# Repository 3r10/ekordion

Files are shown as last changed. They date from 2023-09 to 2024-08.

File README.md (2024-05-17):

# EKordion

## Introduction

Creation of a digital button accordion. *EK* could mean :

- The author's initials.
- *Electronic Keyboard*.

## Hardware

### PCBs *(designed with Kicad)*

+ Right hand PCB
  - 35 Cherry MX switches
  - 5 shift registers (74hc165)
  - Daisy-chain : *not implemented*
  - 6 pin connector to be connected to a micro-controller *(Arduino, ESP32, ...)*
  - Pull-down resistors : pushing buttons means high level
+ Left hand PCB :
  - 24 Cherry MX switches
  - 3 shift registers (74hc165)
  - Daisy-chain : *available*
  - 7 pin output connector to be connected to a micro-controller *(Arduino, ESP32, ...)*
  or another PCB
  - Jumper for CLK INH pull-down
  - 6 pin input connector to be connected to another PCB
  - Jumper for serial input pull-up
  - Pull-up resistors : pushing buttons means low level.

### 3D prints and laser cut *(designed with OpenSCAD)*

+ Right hand
  - 35 button caps to fit the Cherry MX switches
+ Left hand 
  - 24 button caps to fit the CHerry MX switches with offset to allow 
  the required layout.
  - laser cutted grid

## Software

### ESP32 *(IDF environment)*

Polyphonic sound synthesizer.

+ Keyboard inputs via GPIOs
+ Sound output via I2S protocol and external DAC.
+ Control of synthesis parameters via classic bluetooth
+ Synthesis engine :
  - Three instruments : bass, chords, lead
  - Wavetable synthesis
  - 10 polyphonic sounds *(may be more)*
  - Vibrato
  - Small reverberation

### Android app *(Android Studio)*

+ Control of synthesis parameters via classic bluetooth

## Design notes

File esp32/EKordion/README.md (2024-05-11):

```sh
. $HOME/esp/esp-idf/export.sh
sudo chmod a+rw /dev/ttyUSB0
```

### Configure the Project

```sh
idf.py menuconfig
```

### Build and Flash

Build the project and flash it to the board, then run monitor tool to view serial output:

```sh
idf.py -p /dev/ttyUSB0 flash monitor
```

(To exit the serial monitor, type ``Ctrl-]``.)

See the Getting Started Guide for full steps to configure and use ESP-IDF to build projects.

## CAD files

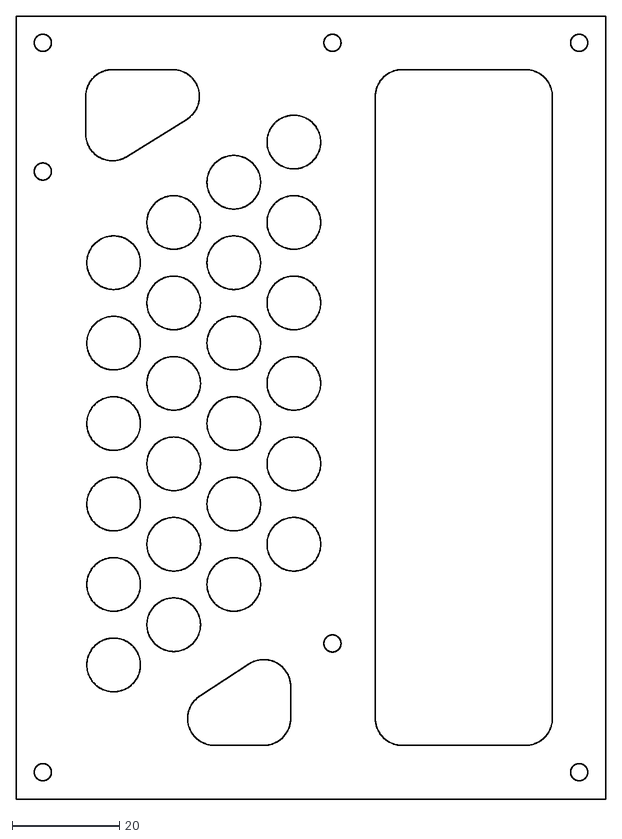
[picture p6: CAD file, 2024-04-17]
openscad/left_hand_buttons/left_hand_buttons_laser_cut.dxf
110.0 x 146.0

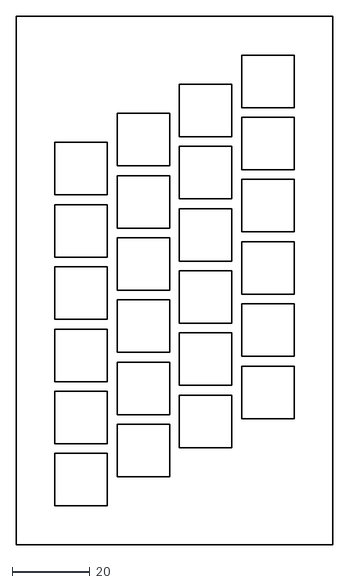
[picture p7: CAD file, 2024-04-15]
openscad/left_hand_soldering_jig/left_hand_soldering_jig.dxf
81.5 x 136.0

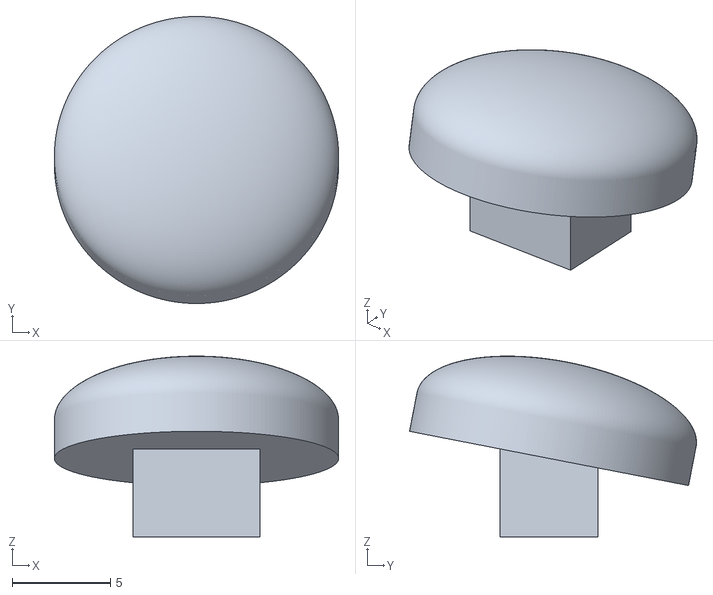
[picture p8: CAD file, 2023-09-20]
openscad/right_hand_button/right_hand_button.stl
14.5 x 14.6 x 9.22

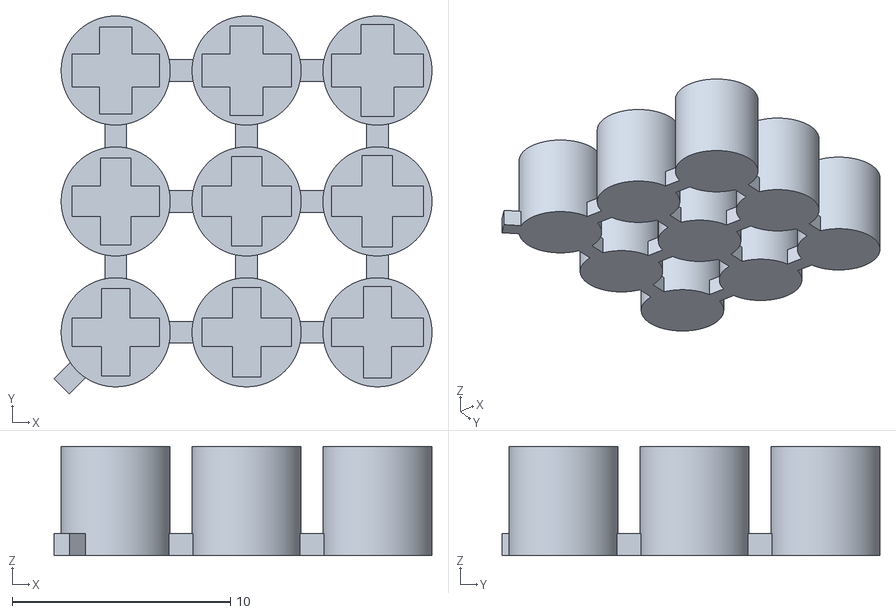
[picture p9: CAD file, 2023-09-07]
openscad/right_hand_button_test.stl
17.3 x 17.3 x 5.00

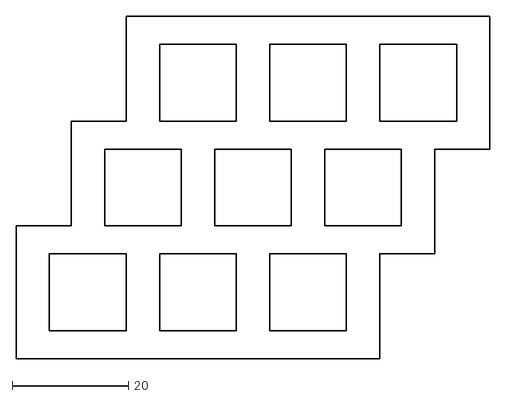
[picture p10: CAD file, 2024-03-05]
openscad/right_hand_soldering_jig/right_hand_soldering_jig.dxf
81.3 x 58.8

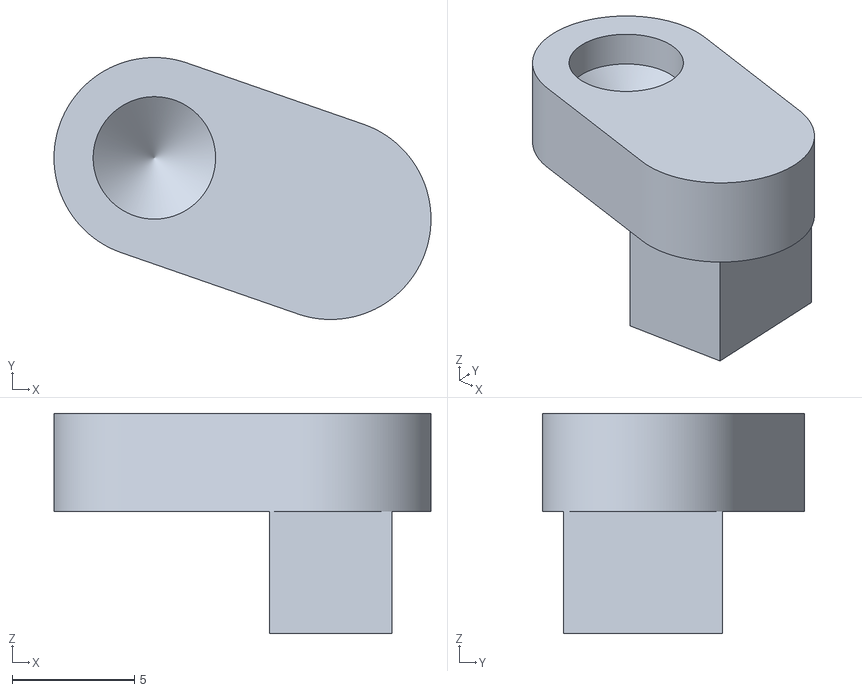
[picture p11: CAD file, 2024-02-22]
openscad/left_hand_buttons/left_hand_buttons_base.stl
15.4 x 10.7 x 9.00

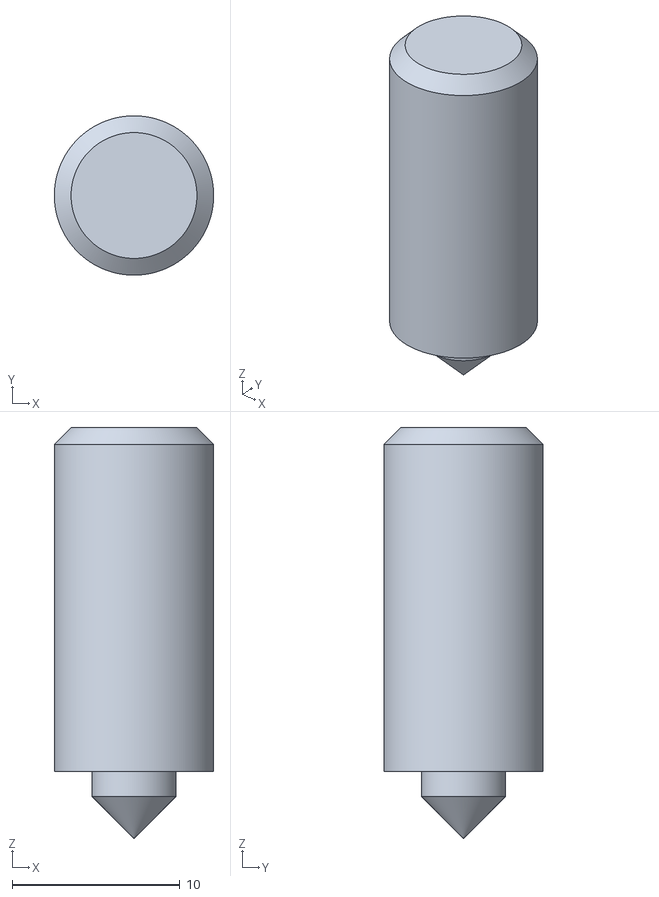
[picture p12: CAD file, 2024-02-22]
openscad/left_hand_buttons/left_hand_buttons_button.stl
9.50 x 9.50 x 24.5

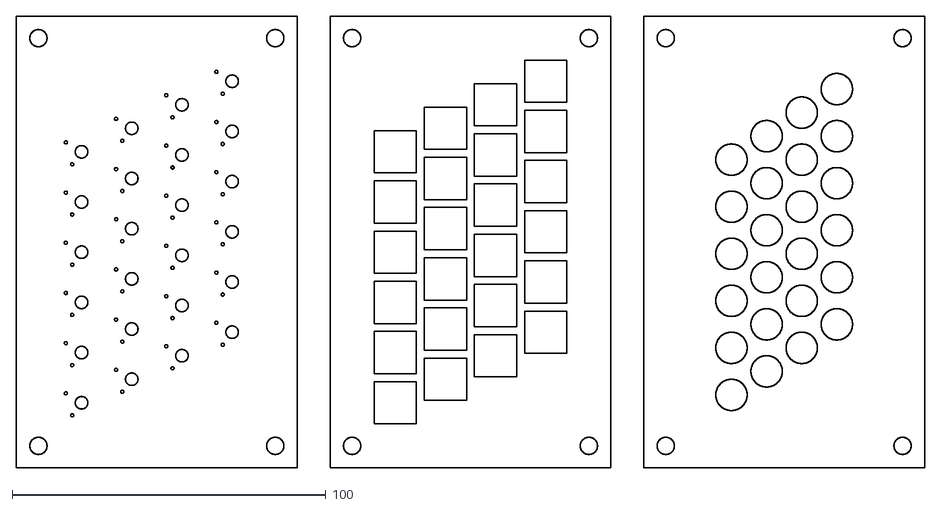
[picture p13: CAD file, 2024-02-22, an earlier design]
openscad/old_designs/left_hand_buttons_laser_cut.dxf
289.5 x 144.0

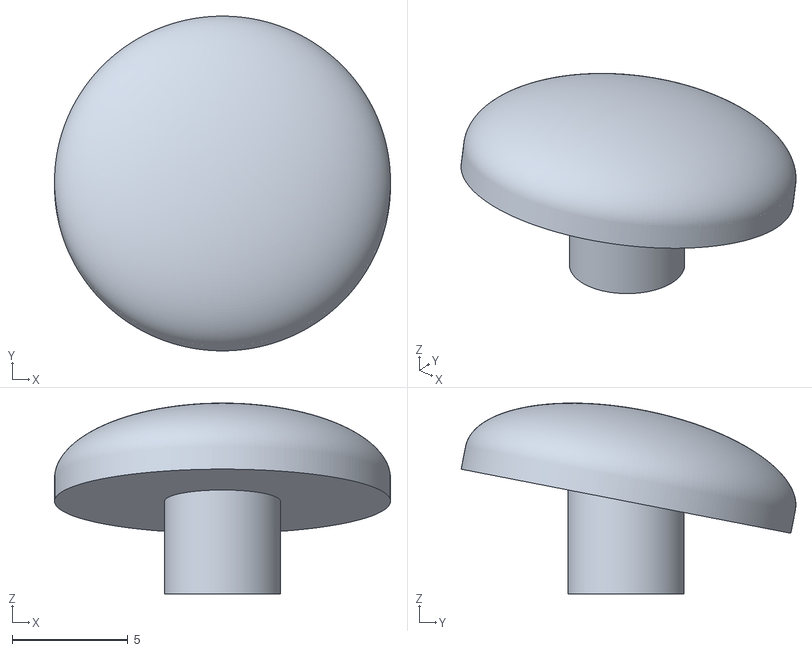
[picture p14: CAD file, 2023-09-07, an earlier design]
openscad/old_designs/right_hand_button.stl
14.5 x 14.4 x 8.23

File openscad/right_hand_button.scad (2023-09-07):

$fn=200;
angle = 11; // 11
buttonDiameter = 14.5;
buttonHeight1 = 3;
buttonHeight2 = 1;
pinDiameter = 5;
pinHeight = 4;
crossLength = 4;
crossWidth = 1.3;
crossDepth = 3.6;

buttonRadius = buttonDiameter/2;
pinRadius = pinDiameter/2;

union() {
	rotate(angle,[-1,0,0])
	translate ([0,0,buttonHeight2])
	union() {
		// top part (tilted)
		scale([1,1,buttonHeight1/buttonRadius])
		difference() {
			sphere(buttonRadius);
			translate([0,0,-buttonRadius]) cube([buttonDiameter,buttonDiameter,buttonDiameter],center=true);
		}
		translate([0,0,-buttonHeight2])
		cylinder(buttonHeight2,buttonRadius,buttonRadius);
	}
	translate([0,0,-pinHeight])
	// interface with CHerry MX switch
	difference() {
		cylinder(pinHeight+pinRadius*tan(angle),pinRadius,pinRadius);
		union() {
			translate([-crossLength/2,-crossWidth/2,-crossDepth]) 
			cube([crossLength,crossWidth,crossDepth*2]);
			translate([-crossWidth/2,-crossLength/2,-crossDepth]) 
			cube([crossWidth,crossLength,crossDepth*2]);
		}
	}
}

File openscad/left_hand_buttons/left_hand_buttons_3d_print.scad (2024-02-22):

$fn=200;

buttonPinDiameter = 9.5;

buttonsNumberX = 4;
buttonsNumberY = 6;
buttonsSpacingX = 11.2;
buttonsSpacingY = 15;
buttonsRankShiftY = 7.5;
buttonsRankShiftZ = 2.5;

buttonsBaseHeight = 13; // 10mm + box width

linkHeight = 4;
plugRadius = 2.5;

switchSpacingX = 16;
switchSpacingY = 16;
switchLengthX = 5;
switchLengthY = 6.5;
switchCrossLength = 4;
switchCrossWidth = 1.3;
switchCrossDepth = 3.6;
switchHeight = 5;





globalDeltaX = (switchSpacingX-buttonsSpacingX)*1.5;
globalDeltaY = (switchSpacingY-buttonsSpacingY)*2.5;

// Deduced from other dimensions
buttonPinRadius = buttonPinDiameter/2;
linkWidth = sqrt(switchLengthX^2+switchLengthY^2);
linkRadius = linkWidth/2;

for (i = [0:buttonsNumberX-1],j = [0:buttonsNumberY-1]) {
// for (i = [buttonsNumberX-1],j = [0]) {
    // Buttons
    buttonX = i*buttonsSpacingX+globalDeltaX;
    buttonY = j*buttonsSpacingY+i*buttonsRankShiftY+globalDeltaY;
    buttonZ = switchHeight;
    translate([buttonX,buttonY,buttonZ])
    union() {
        cylinder(plugRadius,0,plugRadius);
        translate([0,0,plugRadius])
        cylinder(linkHeight-plugRadius,plugRadius,plugRadius);
        h = buttonsBaseHeight+i*buttonsRankShiftZ;
        translate([0,0,linkHeight])
        cylinder(h-1,buttonPinRadius,buttonPinRadius);
        translate([0,0,linkHeight+h-1])
        cylinder(1,buttonPinRadius,buttonPinRadius-1);

    }
    // Switches
    switchX = i*switchSpacingX;
    switchY = j*switchSpacingY+i*buttonsRankShiftY;
    deltaX = switchX-buttonX;
    deltaY = switchY-buttonY;
    angle = atan2(deltaX,deltaY)+90;
    distance = sqrt(deltaX^2+deltaY^2);
    translate([switchX,switchY,0])
    difference() {
	    union() {
            translate([-switchLengthX/2,-switchLengthY/2,0])
        	cube([switchLengthX,switchLengthY,switchHeight]);
            rotate(-angle,[0,0,1])
            translate([0,0,switchHeight])
            difference() {
                union() {
                    translate([0,-linkWidth/2,0])
                    cube([distance,linkWidth,linkHeight]);
                    cylinder(linkHeight,linkRadius,linkRadius);
                    translate([distance,0,0])
                    cylinder(linkHeight,linkRadius,linkRadius);

                }
                union() {
                    translate([distance,0,0])
                    cylinder(plugRadius,0,plugRadius);
                    translate([distance,0,plugRadius])
                    cylinder(linkHeight-plugRadius+1,plugRadius,plugRadius);
                }
            }
        }
		union() {
			cube([switchCrossLength,switchCrossWidth,switchCrossDepth*2],true);
			cube([switchCrossWidth,switchCrossLength,switchCrossDepth*2],true);
		}
	}          
}

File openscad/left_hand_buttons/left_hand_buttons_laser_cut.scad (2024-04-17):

$fn=200;

globalLengthX = 110;
globalLengthY = 146;

centerDeltaX = 35;
centerDeltaY = 73.75;

buttonPinDiameter = 10;

buttonsNumberX = 4;
buttonsNumberY = 6;
buttonsSpacingX = 11.2;
buttonsSpacingY = 15;
buttonsRankShiftY = 7.5;

mountingHolesRadius = 1.6;

buttonPinRadius = buttonPinDiameter/2;

difference() {
    square([globalLengthX,globalLengthY]);
    union() {
        translate([67+buttonPinRadius,10+buttonPinRadius])
        minkowski() {
            square([33-2*buttonPinRadius,126-2*buttonPinRadius]);
            circle(buttonPinRadius);
        }
        minkowski() {
            polygon([
                [29.2,136-buttonPinRadius],
                [18,124],
                [18,136-buttonPinRadius],
            ]);
            circle(buttonPinRadius);
        }
        minkowski() {
            polygon([
                [35+2,10+buttonPinRadius],
                [35+11.2,10+buttonPinRadius],
                [35+11.2,21]
            ]);
            circle(buttonPinRadius);
        }
        translate([5,5])
        circle(mountingHolesRadius);
        translate([5,141])
        circle(mountingHolesRadius);
        translate([5,117])
        circle(mountingHolesRadius);
        translate([59,29])
        circle(mountingHolesRadius);
        translate([59,141])
        circle(mountingHolesRadius);
        translate([105,5])
        circle(mountingHolesRadius);
        translate([105,141])
        circle(mountingHolesRadius);
        translate([centerDeltaX,centerDeltaY])
        union() {
            // circle(1);
            for (i = [0:buttonsNumberX-1],j = [0:buttonsNumberY-1]) {
                buttonX = (1.5-i)*buttonsSpacingX;
                buttonY = (2.5-j)*buttonsSpacingY+(1.5-i)*buttonsRankShiftY;
                translate([buttonX,buttonY])
                circle(buttonPinRadius);
            }
        }
    }
}

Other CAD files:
openscad/left_hand_soldering_jig/left_hand_soldering_jig.scad
openscad/old_designs/left_hand_buttons_laser_cut.scad
openscad/old_designs/right_hand_button_test.scad
openscad/right_hand_button/right_hand_button.scad
openscad/right_hand_button_test.scad
openscad/right_hand_soldering_jig/right_hand_soldering_jig.scad

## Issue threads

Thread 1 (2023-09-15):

tu devrais choisir une license et creer le fichier LICENCE associe a ton projet.

goblinrieur, 2023-09-15:
salut

tu devrais choisir un e license et creer le fichier LICENCE associe a ton projet
Mettre un lien vers ta video et des photos/screenshots dans ton readme egallement ;)

pour les licences y a le choix
-MIT
-nolicence
-gpl*
-etc...

a toi de choisir ;)

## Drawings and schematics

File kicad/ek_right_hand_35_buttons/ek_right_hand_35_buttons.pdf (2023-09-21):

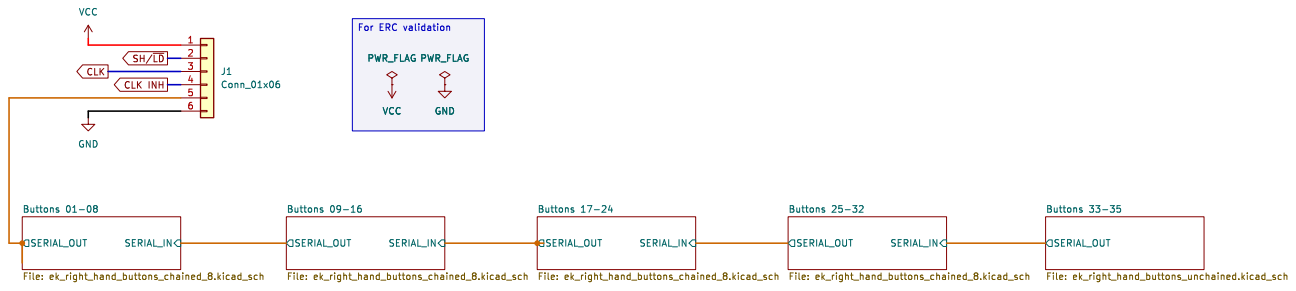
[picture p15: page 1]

SH/~{LD} CLK INH

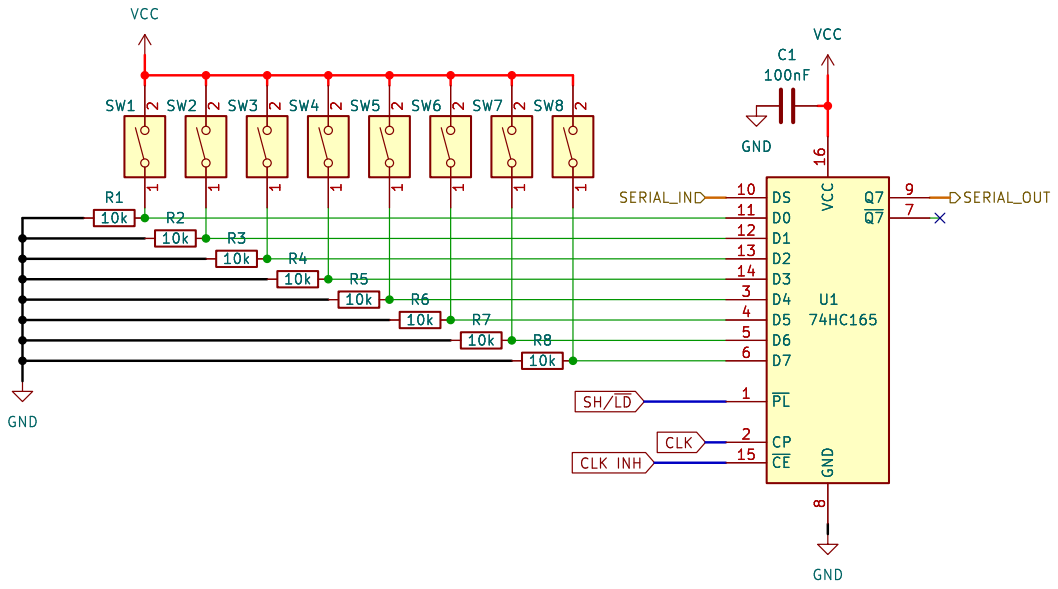
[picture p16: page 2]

1 SW4 2 ~{PL} 1 DS 10 D0 11 D1 12 D2 13 D3 14 ~{CE} 15 VCC 16 CP 2 D4 3 D5 4 D6 5 D7 6 ~{Q7} 7 GND

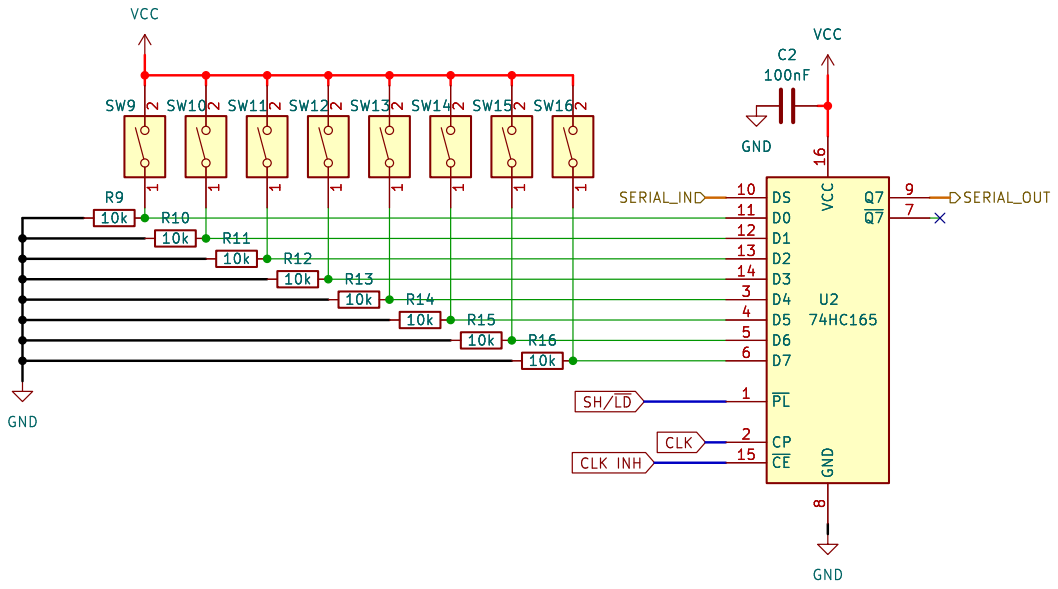
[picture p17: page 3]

1 SW12 2 ~{PL} 1 DS 10 D0 11 D1 12 D2 13 D3 14 ~{CE} 15 VCC 16 CP 2 D4 3 D5 4 D6 5 D7 6 ~{Q7} 7 GND

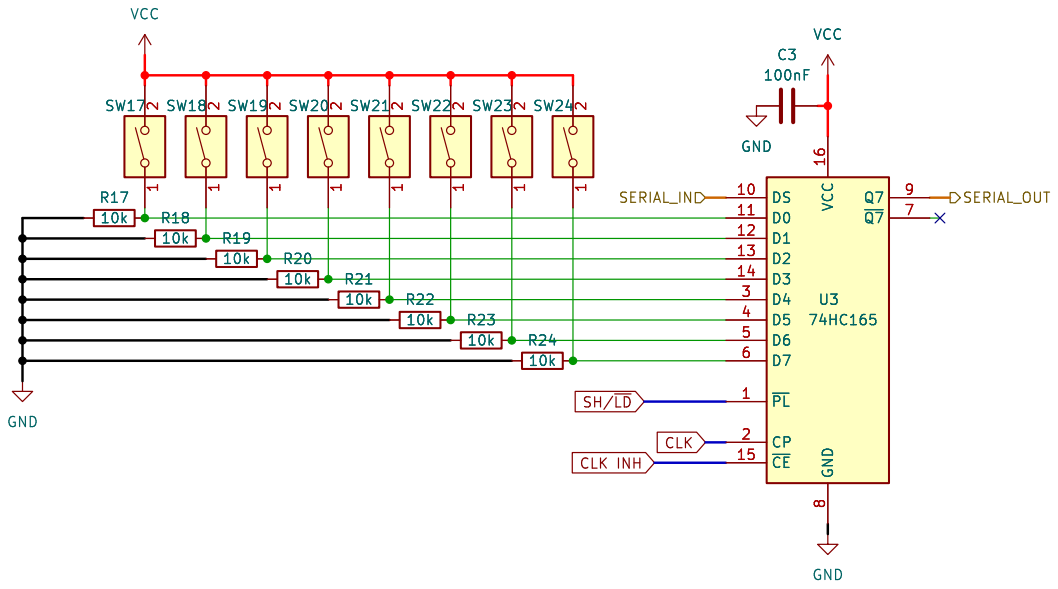
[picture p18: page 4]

1 SW20 2 ~{PL} 1 DS 10 D0 11 D1 12 D2 13 D3 14 ~{CE} 15 VCC 16 CP 2 D4 3 D5 4 D6 5 D7 6 ~{Q7} 7 GND

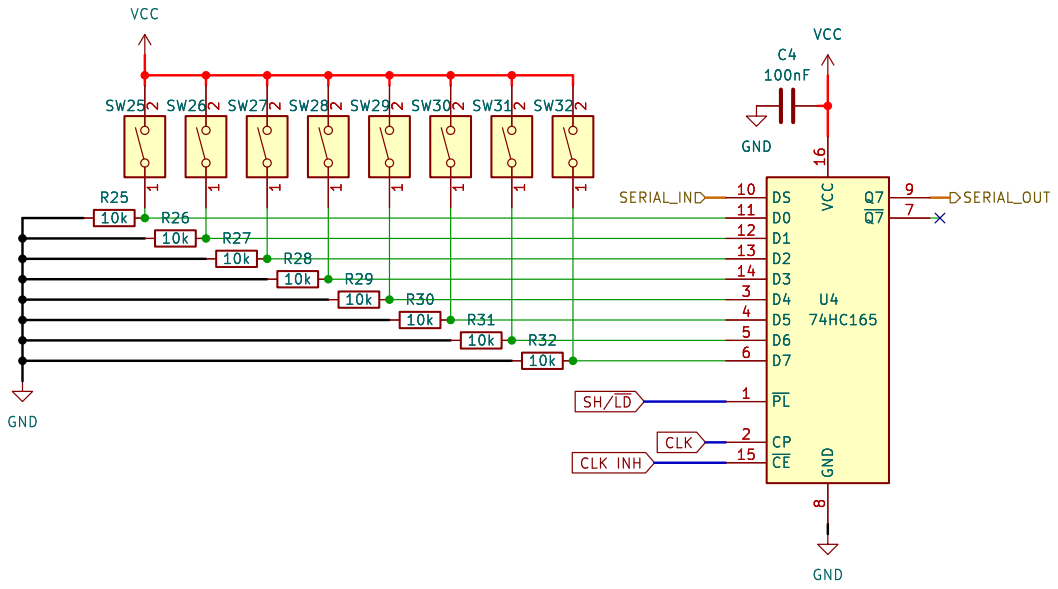
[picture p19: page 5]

1 SW28 2 ~{PL} 1 DS 10 D0 11 D1 12 D2 13 D3 14 ~{CE} 15 VCC 16 CP 2 D4 3 D5 4 D6 5 D7 6 ~{Q7} 7 GND

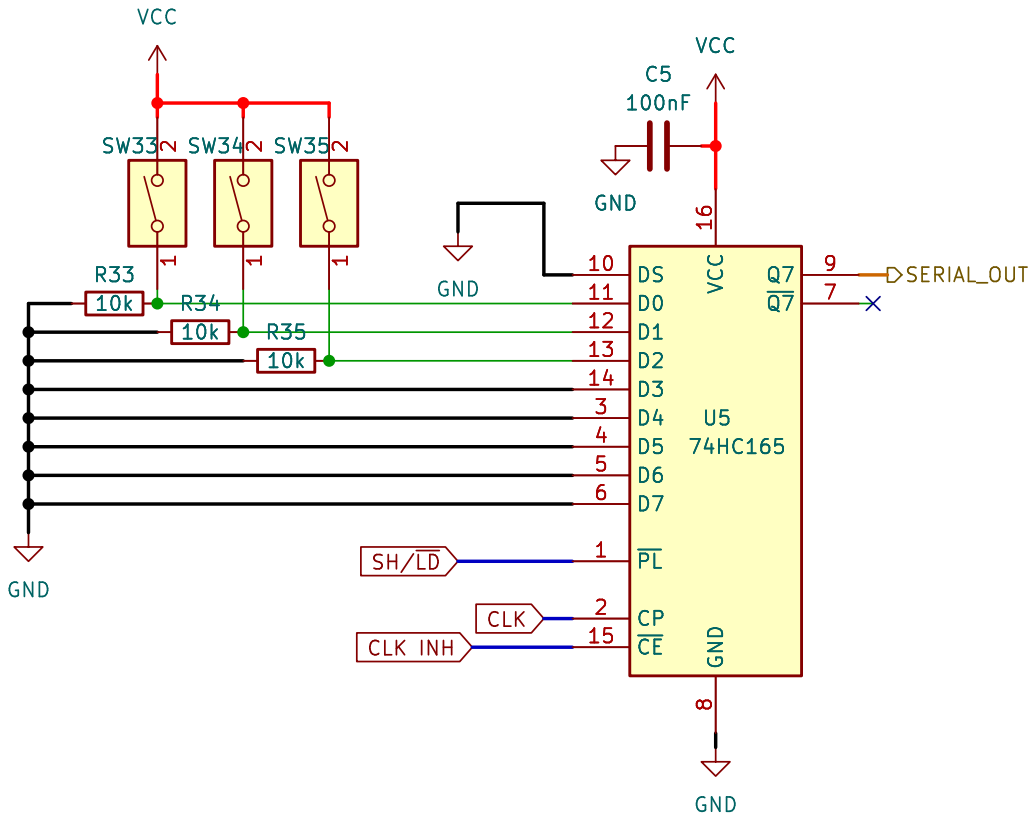
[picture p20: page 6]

SH/~{LD} CLK INH

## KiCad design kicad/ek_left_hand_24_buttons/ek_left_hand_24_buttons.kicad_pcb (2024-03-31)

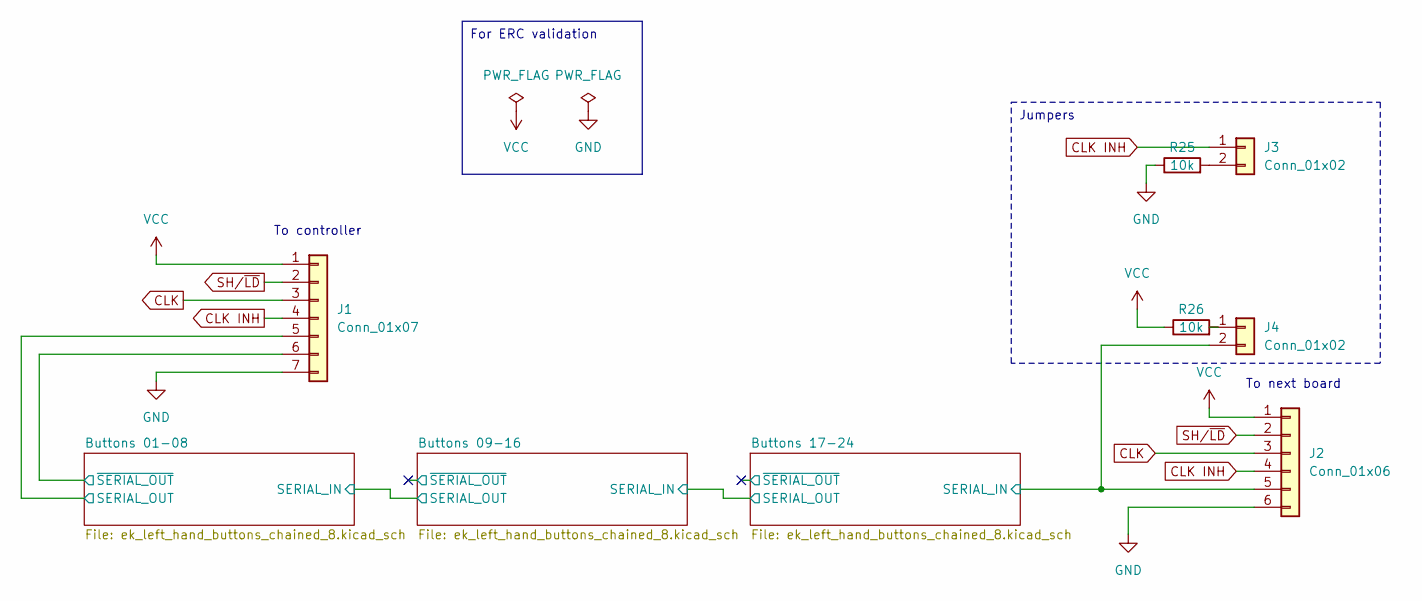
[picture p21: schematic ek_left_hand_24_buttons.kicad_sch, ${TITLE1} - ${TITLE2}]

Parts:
J1: Conn_01x07; PinHeader_1x07_P2.54mm_Vertical
J2: Conn_01x06; PinHeader_1x06_P2.54mm_Vertical
J3, J4: Conn_01x02; PinHeader_1x02_P2.54mm_Vertical
R25, R26: 10k; R_Axial_DIN0207_L6.3mm_D2.5mm_P10.16mm_Horizontal

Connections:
/Buttons 01-08/SERIAL_OUT: J1.5; also elsewhere on the board
/Buttons 01-08/~SERIAL_OUT: J1.6; also elsewhere on the board
/Buttons 17-24/SERIAL_IN: J2.5, J4.2; also elsewhere on the board
CLK: J1.3, J2.3; also elsewhere on the board
CLK INH: J1.4, J2.4, J3.1; also elsewhere on the board
GND: J1.7, J2.6, R25.1; also elsewhere on the board
unnamed: J3.2, R25.2
unnamed: J4.1, R26.2
SH/~LD: J1.2, J2.2; also elsewhere on the board
VCC: J1.1, J2.1, R26.1; also elsewhere on the board

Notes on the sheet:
For ERC validation
Jumpers
To controller
To next board

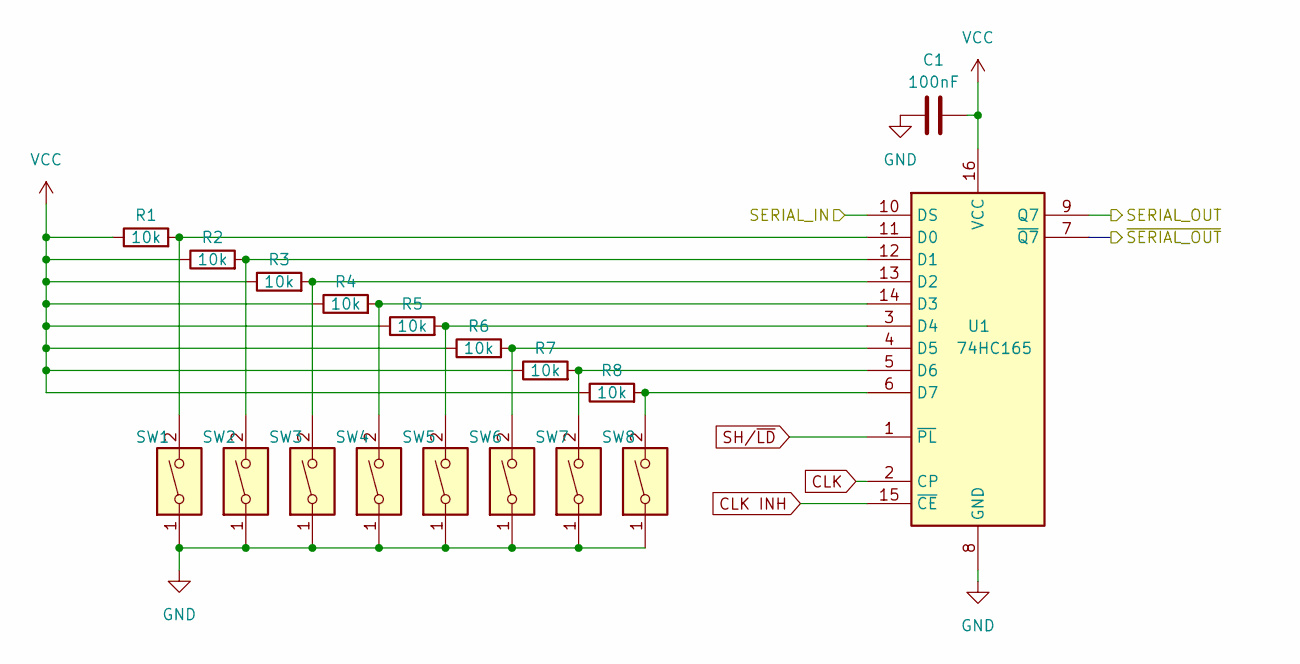
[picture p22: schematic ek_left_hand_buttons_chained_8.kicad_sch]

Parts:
C1: 100nF; C_Rect_L7.0mm_W2.5mm_P5.00mm
R1, R2, R3, R4, R5, R6, R7, R8: 10k; R_Axial_DIN0207_L6.3mm_D2.5mm_P10.16mm_Horizontal
SW1, SW2, SW3, SW4, SW5, SW6, SW7, SW8: SW_Cherry_MX_1.00u_PCB
U1: 74HC165; DIP-16_W7.62mm

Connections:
/Buttons 01-08/SERIAL_IN: U1.10 (DS); also elsewhere on the board
/Buttons 01-08/SERIAL_OUT: U1.9 (Q7); also elsewhere on the board
/Buttons 01-08/~SERIAL_OUT: U1.7 (~Q7); also elsewhere on the board
CLK: U1.2 (CP); also elsewhere on the board
CLK INH: U1.15 (~CE); also elsewhere on the board
GND: C1.2, SW1.1, SW2.1, SW3.1, SW4.1, SW5.1, SW6.1, SW7.1, SW8.1, U1.8 (GND); also elsewhere on the board
unnamed: R1.2, SW1.2, U1.11 (D0)
unnamed: R2.2, SW2.2, U1.12 (D1)
unnamed: R3.2, SW3.2, U1.13 (D2)
unnamed: R4.2, SW4.2, U1.14 (D3)
unnamed: R5.2, SW5.2, U1.3 (D4)
unnamed: R6.2, SW6.2, U1.4 (D5)
unnamed: R7.2, SW7.2, U1.5 (D6)
unnamed: R8.2, SW8.2, U1.6 (D7)
SH/~LD: U1.1 (~PL); also elsewhere on the board
VCC: C1.1, R1.1, R2.1, R3.1, R4.1, R5.1, R6.1, R7.1, R8.1, U1.16 (VCC); also elsewhere on the board

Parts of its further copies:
C2, C3: 100nF; C_Rect_L7.0mm_W2.5mm_P5.00mm
R9, R10, R11, R12, R13, R14, R15, R16, R17, R18, R19, R20, R21, R22, R23, R24: 10k; R_Axial_DIN0207_L6.3mm_D2.5mm_P10.16mm_Horizontal
SW9, SW10, SW11, SW12, SW13, SW14, SW15, SW16, SW17, SW18, SW19, SW20, SW21, SW22, SW23, SW24: SW_Cherry_MX_1.00u_PCB
U2, U3: 74HC165; DIP-16_W7.62mm

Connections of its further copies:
/Buttons 01-08/SERIAL_IN: U2.9 (Q7); also elsewhere on the board
/Buttons 09-16/SERIAL_IN: U2.10 (DS), U3.9 (Q7)
/Buttons 09-16/~SERIAL_OUT: U2.7 (~Q7)
/Buttons 17-24/SERIAL_IN: U3.10 (DS); also elsewhere on the board
/Buttons 17-24/~SERIAL_OUT: U3.7 (~Q7)
CLK: U2.2 (CP), U3.2 (CP); also elsewhere on the board
CLK INH: U2.15 (~CE), U3.15 (~CE); also elsewhere on the board
GND: C2.2, C3.2, SW9.1, SW10.1, SW11.1, SW12.1, SW13.1, SW14.1, SW15.1, SW16.1, SW17.1, SW18.1, SW19.1, SW20.1, SW21.1, SW22.1, SW23.1, SW24.1, U2.8 (GND), U3.8 (GND); also elsewhere on the board
unnamed: R9.2, SW9.2, U2.11 (D0)
unnamed: R10.2, SW10.2, U2.12 (D1)
unnamed: R11.2, SW11.2, U2.13 (D2)
unnamed: R12.2, SW12.2, U2.14 (D3)
unnamed: R13.2, SW13.2, U2.3 (D4)
unnamed: R14.2, SW14.2, U2.4 (D5)
unnamed: R15.2, SW15.2, U2.5 (D6)
unnamed: R16.2, SW16.2, U2.6 (D7)
unnamed: R17.2, SW17.2, U3.11 (D0)
unnamed: R18.2, SW18.2, U3.12 (D1)
unnamed: R19.2, SW19.2, U3.13 (D2)
unnamed: R20.2, SW20.2, U3.14 (D3)
unnamed: R21.2, SW21.2, U3.3 (D4)
unnamed: R22.2, SW22.2, U3.4 (D5)
unnamed: R23.2, SW23.2, U3.5 (D6)
unnamed: R24.2, SW24.2, U3.6 (D7)
SH/~LD: U2.1 (~PL), U3.1 (~PL); also elsewhere on the board
VCC: C2.1, C3.1, R9.1, R10.1, R11.1, R12.1, R13.1, R14.1, R15.1, R16.1, R17.1, R18.1, R19.1, R20.1, R21.1, R22.1, R23.1, R24.1, U2.16 (VCC), U3.16 (VCC); also elsewhere on the board

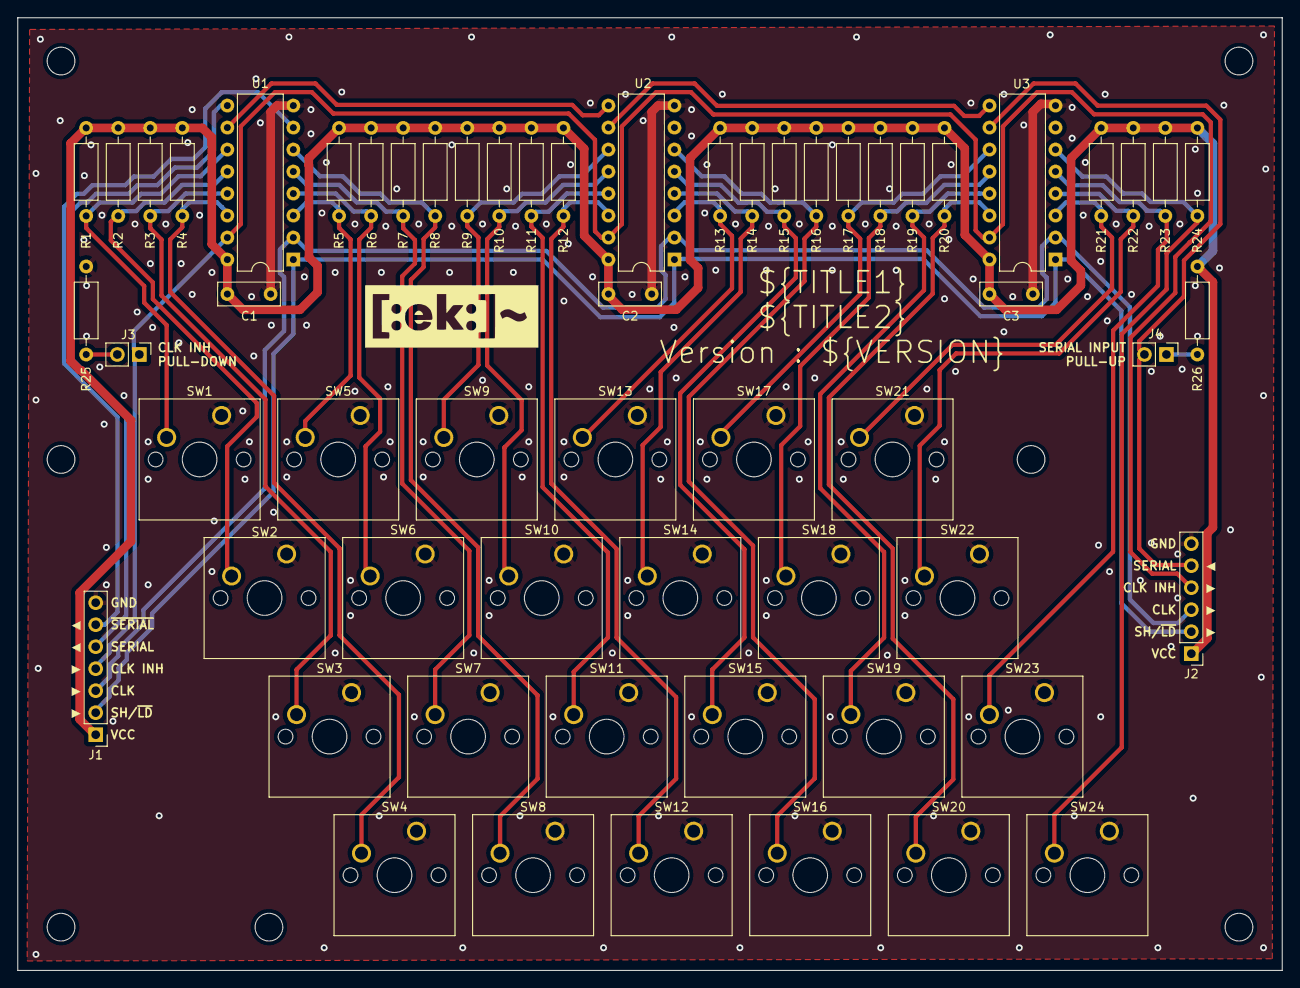
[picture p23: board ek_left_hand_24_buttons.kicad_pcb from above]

Board: 2 copper layers, 146.0 x 110.0 mm, 67 parts (0 on the bottom side), 36 nets.

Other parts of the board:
M1, M1#2, M2, M3, M4, M4#2, M4#3: MountingHole_3.2mm_M3

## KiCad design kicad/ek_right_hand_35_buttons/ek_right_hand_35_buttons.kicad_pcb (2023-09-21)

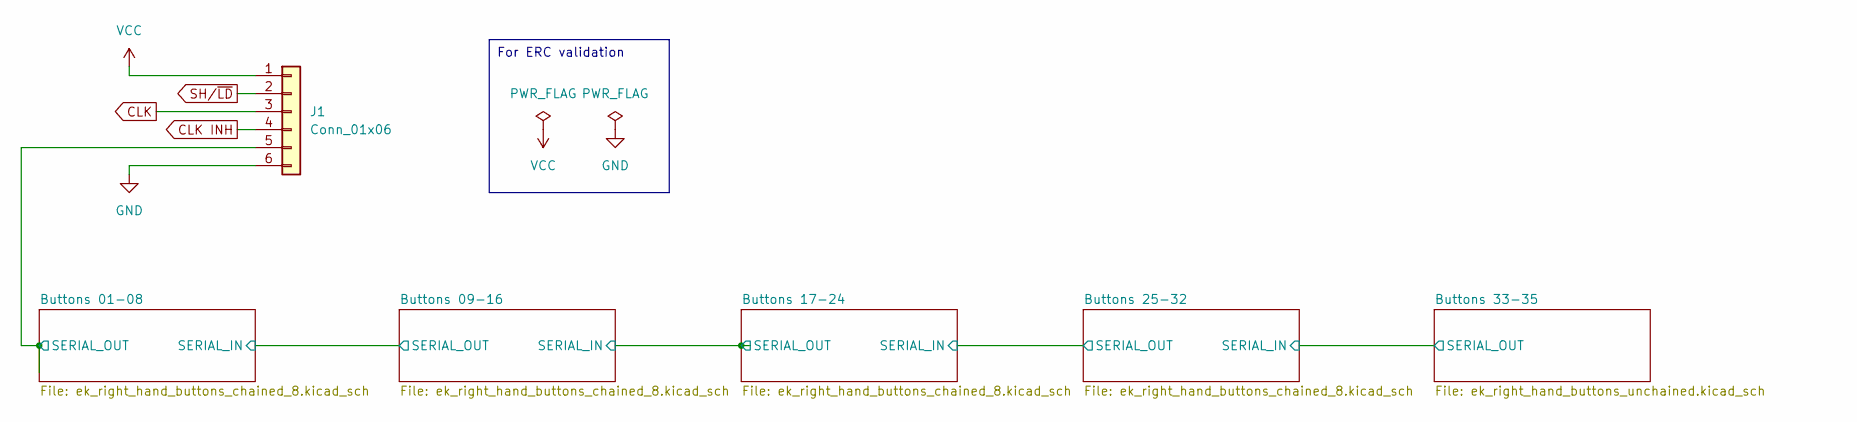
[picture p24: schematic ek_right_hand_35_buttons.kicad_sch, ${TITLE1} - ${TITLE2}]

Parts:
J1: Conn_01x06; PinHeader_1x06_P2.54mm_Vertical

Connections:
/Buttons 01-08/SERIAL_OUT: J1.5; also elsewhere on the board
CLK: J1.3; also elsewhere on the board
CLK INH: J1.4; also elsewhere on the board
SH/~LD: J1.2; also elsewhere on the board
VCC: J1.1; also elsewhere on the board

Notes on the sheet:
For ERC validation

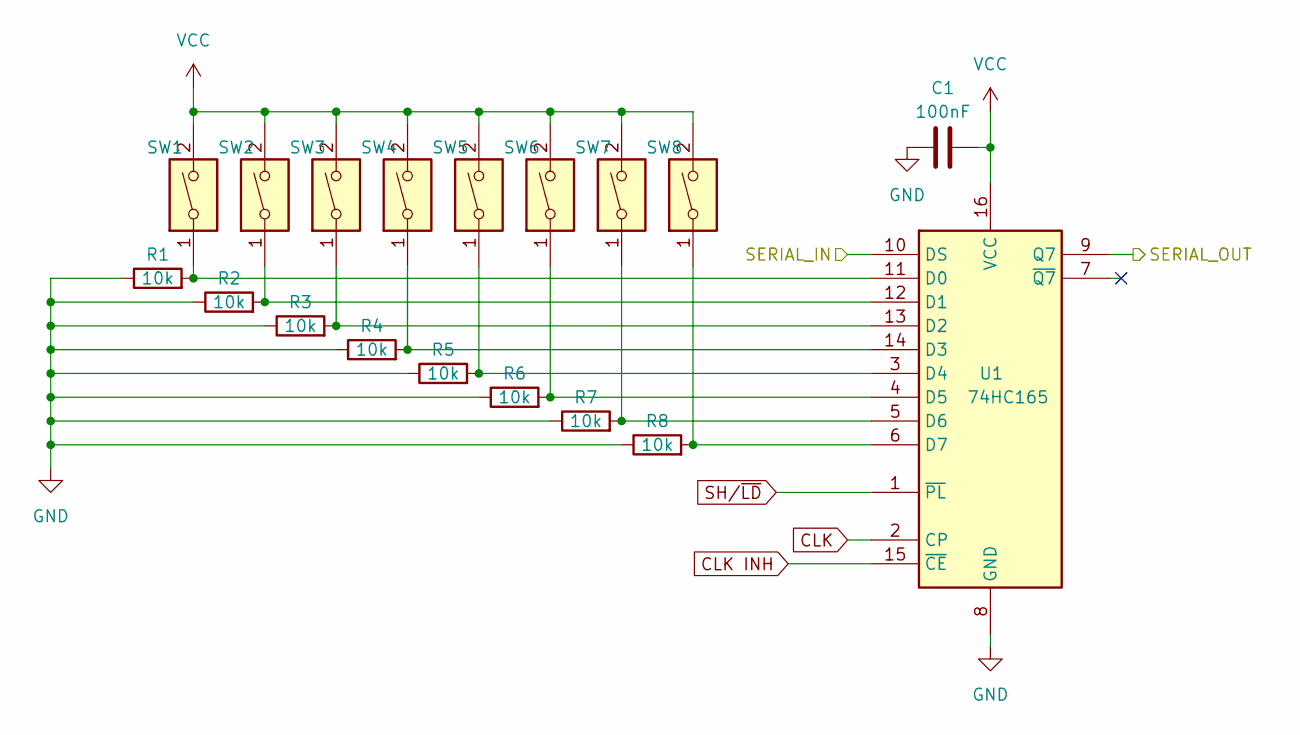
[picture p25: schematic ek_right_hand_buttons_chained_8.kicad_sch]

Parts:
C1: 100nF; C_Rect_L7.0mm_W2.5mm_P5.00mm
R1, R2, R3, R4, R5, R6, R7, R8: 10k; R_Axial_DIN0207_L6.3mm_D2.5mm_P10.16mm_Horizontal
SW1, SW2, SW3, SW4, SW5, SW6, SW7, SW8: SW_Cherry_MX_1.00u_PCB
U1: 74HC165; DIP-16_W7.62mm

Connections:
/Buttons 01-08/SERIAL_OUT: U1.9 (Q7); also elsewhere on the board
CLK: U1.2 (CP); also elsewhere on the board
CLK INH: U1.15 (~CE); also elsewhere on the board
unnamed: R1.2, SW1.1, U1.11 (D0)
unnamed: R2.2, SW2.1, U1.12 (D1)
unnamed: R3.2, SW3.1, U1.13 (D2)
SH/~LD: U1.1 (~PL); also elsewhere on the board
VCC: C1.1, SW1.2, SW2.2, SW3.2, SW4.2, SW5.2, SW6.2, SW7.2, SW8.2, U1.16 (VCC); also elsewhere on the board

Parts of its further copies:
C2, C3, C4: 100nF; C_Rect_L7.0mm_W2.5mm_P5.00mm
R9, R10, R11, R12, R13, R14, R15, R16, R17, R18, R19, R20, R21, R22, R23, R24, R25, R26, R27, R28, R29, R30, R31, R32: 10k; R_Axial_DIN0207_L6.3mm_D2.5mm_P10.16mm_Horizontal
SW9, SW10, SW11, SW12, SW13, SW14, SW15, SW16, SW17, SW18, SW19, SW20, SW21, SW22, SW23, SW24, SW25, SW26, SW27, SW28, SW29, SW30, SW31, SW32: SW_Cherry_MX_1.00u_PCB
U2, U3, U4: 74HC165; DIP-16_W7.62mm

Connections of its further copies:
/Buttons 09-16/SERIAL_IN: U2.10 (DS), U3.9 (Q7)
/Buttons 17-24/SERIAL_IN: U3.10 (DS), U4.9 (Q7)
/Buttons 25-32/SERIAL_IN: U4.10 (DS); also elsewhere on the board
CLK: U2.2 (CP), U3.2 (CP), U4.2 (CP); also elsewhere on the board
CLK INH: U2.15 (~CE), U3.15 (~CE), U4.15 (~CE); also elsewhere on the board
unnamed: R9.2, SW9.1, U2.11 (D0)
unnamed: R10.2, SW10.1, U2.12 (D1)
unnamed: R11.2, SW11.1, U2.13 (D2)
unnamed: R12.2, SW12.1, U2.14 (D3)
unnamed: R13.2, SW13.1, U2.3 (D4)
unnamed: R14.2, SW14.1, U2.4 (D5)
unnamed: R15.2, SW15.1, U2.5 (D6)
unnamed: R16.2, SW16.1, U2.6 (D7)
unnamed: R17.2, SW17.1, U3.11 (D0)
unnamed: R18.2, SW18.1, U3.12 (D1)
unnamed: R19.2, SW19.1, U3.13 (D2)
unnamed: R20.2, SW20.1, U3.14 (D3)
unnamed: R21.2, SW21.1, U3.3 (D4)
unnamed: R22.2, SW22.1, U3.4 (D5)
unnamed: R23.2, SW23.1, U3.5 (D6)
unnamed: R24.2, SW24.1, U3.6 (D7)
unnamed: R25.2, SW25.1, U4.11 (D0)
unnamed: R26.2, SW26.1, U4.12 (D1)
unnamed: R27.2, SW27.1, U4.13 (D2)
unnamed: R28.2, SW28.1, U4.14 (D3)
unnamed: R29.2, SW29.1, U4.3 (D4)
unnamed: R30.2, SW30.1, U4.4 (D5)
unnamed: R31.2, SW31.1, U4.5 (D6)
unnamed: R32.2, SW32.1, U4.6 (D7)
SH/~LD: U2.1 (~PL), U3.1 (~PL), U4.1 (~PL); also elsewhere on the board
VCC: C2.1, C3.1, C4.1, SW9.2, SW10.2, SW11.2, SW12.2, SW13.2, SW14.2, SW15.2, SW16.2, SW17.2, SW18.2, SW19.2, SW20.2, SW21.2, SW22.2, SW23.2, SW24.2, SW25.2, SW26.2, SW27.2, SW28.2, SW29.2, SW30.2, SW31.2, SW32.2, U2.16 (VCC), U3.16 (VCC), U4.16 (VCC); also elsewhere on the board

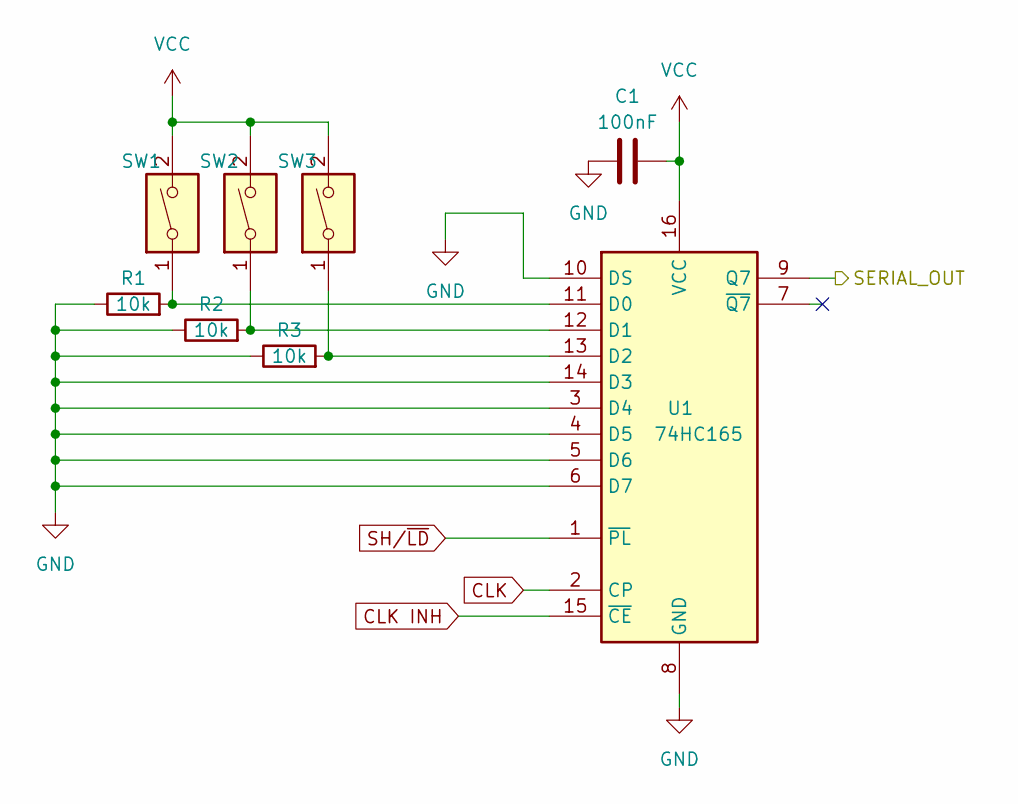
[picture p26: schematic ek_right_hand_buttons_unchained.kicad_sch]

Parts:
C1: 100nF; C_Rect_L7.0mm_W2.5mm_P5.00mm
R1, R2, R3: 10k; R_Axial_DIN0207_L6.3mm_D2.5mm_P10.16mm_Horizontal
SW1, SW2, SW3: SW_Cherry_MX_1.00u_PCB
U1: 74HC165; DIP-16_W7.62mm

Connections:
/Buttons 01-08/SERIAL_OUT: U1.9 (Q7); also elsewhere on the board
CLK: U1.2 (CP); also elsewhere on the board
CLK INH: U1.15 (~CE); also elsewhere on the board
unnamed: R1.2, SW1.1, U1.11 (D0)
unnamed: R2.2, SW2.1, U1.12 (D1)
unnamed: R3.2, SW3.1, U1.13 (D2)
SH/~LD: U1.1 (~PL); also elsewhere on the board
VCC: C1.1, SW1.2, SW2.2, SW3.2, U1.16 (VCC); also elsewhere on the board

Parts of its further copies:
C2, C3, C4, C5: 100nF; C_Rect_L7.0mm_W2.5mm_P5.00mm
R9, R10, R11, R17, R18, R19, R25, R26, R27, R33, R34, R35: 10k; R_Axial_DIN0207_L6.3mm_D2.5mm_P10.16mm_Horizontal
SW9, SW10, SW11, SW17, SW18, SW19, SW25, SW26, SW27, SW33, SW34, SW35: SW_Cherry_MX_1.00u_PCB
U2, U3, U4, U5: 74HC165; DIP-16_W7.62mm

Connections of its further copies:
/Buttons 09-16/SERIAL_IN: U2.10 (DS), U3.9 (Q7)
/Buttons 17-24/SERIAL_IN: U3.10 (DS), U4.9 (Q7)
/Buttons 25-32/SERIAL_IN: U4.10 (DS), U5.9 (Q7)
CLK: U2.2 (CP), U3.2 (CP), U4.2 (CP), U5.2 (CP); also elsewhere on the board
CLK INH: U2.15 (~CE), U3.15 (~CE), U4.15 (~CE), U5.15 (~CE); also elsewhere on the board
unnamed: R9.2, SW9.1, U2.11 (D0)
unnamed: R10.2, SW10.1, U2.12 (D1)
unnamed: R11.2, SW11.1, U2.13 (D2)
unnamed 12: U2.14 (D3); also elsewhere on the board
unnamed 13: U2.3 (D4); also elsewhere on the board
unnamed 14: U2.4 (D5); also elsewhere on the board
unnamed 15: U2.5 (D6); also elsewhere on the board
unnamed 16: U2.6 (D7); also elsewhere on the board
unnamed: R17.2, SW17.1, U3.11 (D0)
unnamed: R18.2, SW18.1, U3.12 (D1)
unnamed: R19.2, SW19.1, U3.13 (D2)
unnamed 20: U3.14 (D3); also elsewhere on the board
unnamed 21: U3.3 (D4); also elsewhere on the board
unnamed 22: U3.4 (D5); also elsewhere on the board
unnamed 23: U3.5 (D6); also elsewhere on the board
unnamed 24: U3.6 (D7); also elsewhere on the board
unnamed: R25.2, SW25.1, U4.11 (D0)
unnamed: R26.2, SW26.1, U4.12 (D1)
unnamed: R27.2, SW27.1, U4.13 (D2)
unnamed 28: U4.14 (D3); also elsewhere on the board
unnamed 29: U4.3 (D4); also elsewhere on the board
unnamed 30: U4.4 (D5); also elsewhere on the board
unnamed 31: U4.5 (D6); also elsewhere on the board
unnamed 32: U4.6 (D7); also elsewhere on the board
unnamed: R33.2, SW33.1, U5.11 (D0)
unnamed: R34.2, SW34.1, U5.12 (D1)
unnamed: R35.2, SW35.1, U5.13 (D2)
SH/~LD: U2.1 (~PL), U3.1 (~PL), U4.1 (~PL), U5.1 (~PL); also elsewhere on the board
VCC: C2.1, C3.1, C4.1, C5.1, SW9.2, SW10.2, SW11.2, SW17.2, SW18.2, SW19.2, SW25.2, SW26.2, SW27.2, SW33.2, SW34.2, SW35.2, U2.16 (VCC), U3.16 (VCC), U4.16 (VCC), U5.16 (VCC); also elsewhere on the board

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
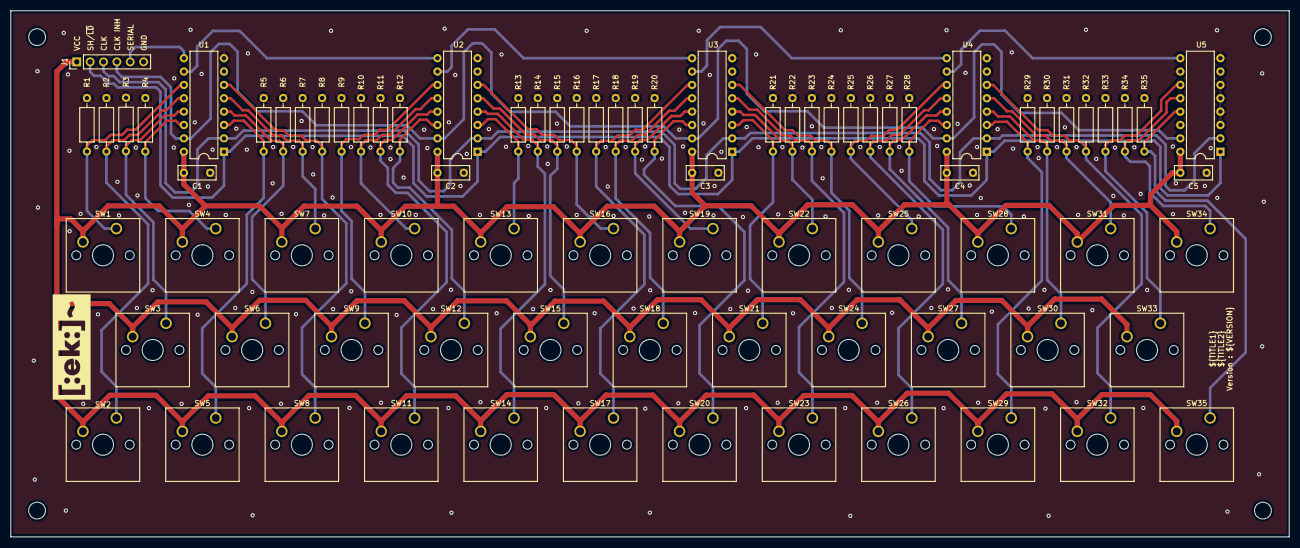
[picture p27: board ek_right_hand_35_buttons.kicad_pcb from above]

Board: 2 copper layers, 243.0 x 100.0 mm, 85 parts (0 on the bottom side), 45 nets.

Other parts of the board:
M1, M2, M3, M4: MountingHole_3.2mm_M3

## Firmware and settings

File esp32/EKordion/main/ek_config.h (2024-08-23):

#include <math.h>
#include <inttypes.h>
#include "freertos/FreeRTOS.h"
#include "freertos/task.h"
#include "driver/gpio.h"
#include "esp_system.h"
#include "esp_log.h"

#ifndef EK_CONFIG_H
#define EK_CONFIG_H

static const char* TAG = "EKordion";

/* TIMING STATS */

// #define MEASURE_CPU_USAGE false
#define MEASURE_CPU_USAGE true

/* BLUETOOTH */
#define EK_BLUETOOTH_SERVER_NAME "EKordion server"
#define EK_BLUETOOTH_DEVICE_NAME "EKordion device"
#define CHANGE_CUSTOM_TABLE      0
#define CHANGE_TONALITY          1
#define CHANGE_CHORD_PATTERN     2
#define CHANGE_LFO_TABLE         3
#define CHANGE_LFO_FREQUENCY     4
#define CHANGE_REVERB_FEEDBACK   5
#define CHANGE_REVERB_DAMPING    6
#define CHANGE_REVERB_VOLUME     7
#define CHANGE_TABLE             8
#define CHANGE_RESOLUTION        9
#define CHANGE_DOWNSAMPLING      10
#define CHANGE_OCTAVE            11
#define CHANGE_MONOPOLY_MODE     12
#define CHANGE_ARPEGGIO_DURATION 13
#define CHANGE_ARPEGGIATOR       14
#define CHANGE_VIBRATO           15
#define CHANGE_N_OSCILLATORS     16
#define CHANGE_DETUNE_FACTOR     17
#define CHANGE_ENVELOPE_A        18
#define CHANGE_ENVELOPE_D        19
#define CHANGE_ENVELOPE_S        20
#define CHANGE_ENVELOPE_R        21
#define CHANGE_FILTER_LOW_F      22
#define CHANGE_FILTER_HIGH_F     23
#define CHANGE_FILTER_Q          24
#define CHANGE_FILTER_MOD_A      25
#define CHANGE_FILTER_MOD_D      26
#define CHANGE_FILTER_MOD_S      27
#define CHANGE_FILTER_MOD_R      28
#define CHANGE_TREMOLO           29
#define CHANGE_DRY_VOLUME        30
#define CHANGE_WET_VOLUME        31
#define N_CHANGE_FUNCTIONS       32

/* GENERAL I2S PARAMETERS */
#define SAMPLE_RATE     44100
#define DMA_BUF_LEN     32
#define DMA_NUM_BUF     2
#define I2S_NUM         I2S_NUM_0

/* KEYBOARDS PINS*/
#define GPIO_SHIFT_LOAD   GPIO_NUM_15
#define GPIO_CLK          GPIO_NUM_2
#define GPIO_LEFT_SERIAL  GPIO_NUM_4
#define GPIO_RIGHT_SERIAL GPIO_NUM_16

/* KEYBOARD */
#define N_RIGHT_SWITCHES 40
#define N_LEFT_SWITCHES 24

#endif

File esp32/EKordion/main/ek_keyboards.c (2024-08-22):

#include "ek_keyboards.h"
#include "ek_synth.h"

#define BASS_CHANNEL 0
#define CHORDS_CHANNEL 1
#define LEAD_CHANNEL 2

static uint8_t left_switch_to_channel[N_LEFT_SWITCHES] = {
    BASS_CHANNEL, BASS_CHANNEL, CHORDS_CHANNEL, CHORDS_CHANNEL,
    BASS_CHANNEL, BASS_CHANNEL, CHORDS_CHANNEL, CHORDS_CHANNEL,
    BASS_CHANNEL, BASS_CHANNEL, CHORDS_CHANNEL, CHORDS_CHANNEL,
    BASS_CHANNEL, BASS_CHANNEL, CHORDS_CHANNEL, CHORDS_CHANNEL,
    BASS_CHANNEL, BASS_CHANNEL, CHORDS_CHANNEL, CHORDS_CHANNEL,
    BASS_CHANNEL, BASS_CHANNEL, CHORDS_CHANNEL, CHORDS_CHANNEL,
};

static uint8_t left_switch_to_button[N_LEFT_SWITCHES] = {
     5, 0, 5, 0, 
     7, 2, 7, 2,
     9, 4, 9, 4,
    11, 6,11, 6,
     1, 8, 1, 8, 
     3,10, 3,10,
};

static uint8_t right_switches_on_off[N_RIGHT_SWITCHES] = {0};
static uint8_t left_switches_on_off[N_LEFT_SWITCHES] = {0};

void ek_keyboards_init() {
    gpio_reset_pin(GPIO_SHIFT_LOAD);
    gpio_set_direction(GPIO_SHIFT_LOAD, GPIO_MODE_OUTPUT);
    gpio_reset_pin(GPIO_CLK);
    gpio_set_direction(GPIO_CLK, GPIO_MODE_OUTPUT);
    gpio_reset_pin(GPIO_RIGHT_SERIAL);
    gpio_set_direction(GPIO_RIGHT_SERIAL, GPIO_MODE_INPUT);
    gpio_reset_pin(GPIO_LEFT_SERIAL);
    gpio_set_direction(GPIO_LEFT_SERIAL, GPIO_MODE_INPUT);
}

void ek_keyboards_get_data() {
    uint8_t on_off; 

    gpio_set_level(GPIO_SHIFT_LOAD,0);
    gpio_set_level(GPIO_SHIFT_LOAD,1);
    for (int i=0; i<N_RIGHT_SWITCHES; i++) {
        // endianness correction
        int i_switch = i+7-2*(i%8);
        on_off = gpio_get_level(GPIO_RIGHT_SERIAL);
        if (on_off!=right_switches_on_off[i_switch]) {
            right_switches_on_off[i_switch] = on_off;
            // i_button = i_switch (strict correspondance here)
            if (on_off) ek_synth_button_on(LEAD_CHANNEL,i_switch);
            else ek_synth_button_off(LEAD_CHANNEL,i_switch);
        }
        gpio_set_level(GPIO_CLK,1);
        gpio_set_level(GPIO_CLK,0);
    }
    gpio_set_level(GPIO_SHIFT_LOAD,0);
    gpio_set_level(GPIO_SHIFT_LOAD,1);
    for (int i=0; i<N_LEFT_SWITCHES; i++) {
        // endianness correction and mapping
        int i_switch = i+7-2*(i%8);
        on_off = gpio_get_level(GPIO_LEFT_SERIAL);
        if (on_off!=left_switches_on_off[i_switch]) {
            int i_channel = left_switch_to_channel[i_switch];
            int i_button = left_switch_to_button[i_switch];
            left_switches_on_off[i_switch] = on_off;
            if (on_off) ek_synth_button_on(i_channel,i_button);
            else ek_synth_button_off(i_channel,i_button);
        }
        gpio_set_level(GPIO_CLK,1);
        gpio_set_level(GPIO_CLK,0);
    }
}

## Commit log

2023-09-05 Righ hand 35 first schematic
    [ek_right_hand_35_buttons.kicad_pcb, ek_right_hand_35_buttons.kicad_sch, ek_right_hand_buttons_chained_8.kicad_sch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]
2023-09-05 Righ hand 35 first PCB with very bad tracks
    [ek_right_hand_35_buttons.kicad_pcb, ek_right_hand_35_buttons.kicad_sch]
2023-09-06 Right hand 35 first PCB with better tracks
    [ek_right_hand_35_buttons.kicad_pcb]
2023-09-07 First right hand button test
    [right_hand_button.scad, right_hand_button_test.scad, right_hand_button_test.stl]
2023-09-07 Right hand 35 first PCB with copper pour
    [ek_right_hand_35_buttons.kicad_pcb, ek_right_hand_35_buttons.kicad_sch]
2023-09-09 Right hand 35 first PCB with vias, holes & labels
    [ek_right_hand_35_buttons.kicad_pcb, ek_right_hand_35_buttons.kicad_sch]
2023-09-10 Right hand 35 condensed positions
    [ek_right_hand_35_buttons.kicad_pcb]
2023-09-11 Right hand 35 better vias
    [ek_right_hand_35_buttons.kicad_pcb]
2023-09-15 Right hand 35 vias and gerber
    [ek_right_hand_35_buttons-B_Cu.gbr, ek_right_hand_35_buttons-B_Mask.gbr, ek_right_hand_35_buttons-B_Paste.gbr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]
2023-09-20 Right hand button w/ stronger pin
    [right_hand_button.scad, right_hand_button.stl, right_hand_button_test.scad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]
2024-02-20 Reorga Openscad
    [right_hand_button.scad, right_hand_button.stl]
2024-02-22 Laft hand tests
    [left_hand_buttons_3d_print.scad, left_hand_buttons_base.stl, left_hand_buttons_button.stl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]
2024-03-05 Right hand soldering jig
    [right_hand_soldering_jig.dxf, right_hand_soldering_jig.scad]
2024-03-24 Left hand 24 buttons (first version)
    [ek_left_hand_24_buttons.kicad_pcb, ek_left_hand_24_buttons.kicad_sch, ek_left_hand_buttons_chained_8.kicad_sch]
2024-03-24 Left hand 24 buttons delete previous version
2024-03-31 Left Hand 24 before vias
    [ek_left_hand_24_buttons.kicad_pcb]
2024-03-31 Left Hand 24 after vias
    [ek_left_hand_24_buttons.kicad_pcb]
2024-03-31 Left Hand 24 gerber output
    [ek_left_hand_24_buttons-B_Cu.gbr, ek_left_hand_24_buttons-B_Mask.gbr, ek_left_hand_24_buttons-B_Paste.gbr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]
2024-04-15 Left hand laser cut proto
    [left_hand_buttons_laser_cut.dxf, left_hand_buttons_laser_cut.scad]
2024-04-15 Left hand soldering jig
    [left_hand_soldering_jig.dxf, left_hand_soldering_jig.scad]
2024-04-16 Left hand laser cut
    [left_hand_buttons_laser_cut.scad]
2024-05-11 ESP32 synth first draft
2024-08-18 ADSR controlled filters (+ a static version if necessary at some point)
